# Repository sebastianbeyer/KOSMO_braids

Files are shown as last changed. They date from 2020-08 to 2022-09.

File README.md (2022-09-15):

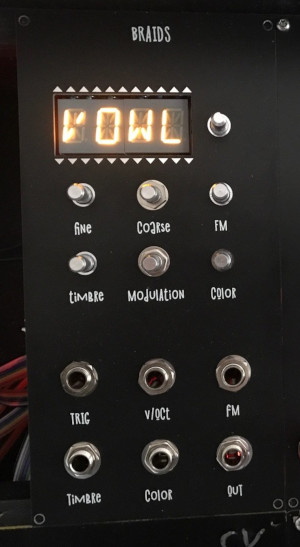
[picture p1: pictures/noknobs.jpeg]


This is a KOSMO (Look Mum No Computer) version of the Mutable instruments
braids, based on the through-hole version done by
[sound-force.nl](http://sound-force.nl/?page_id=3179).
It has only 12 bits resolution in the output because the chip is easier to work
with and cheaper.

## Changes to original

This project is so far only different to the soundforce version in that I removed the
3.5mm jack sockets and replaced them with molex connectors to get them connected to the
larger 6.3mm jack sockets that KOSMO uses.
And I made the larger KOSMO panel.

This version is still with the old (soundforce-1.1) Version of the soundforce board, without the
termination series resistors on the SPI lines. I had no problems with this, but
I have not changed anything on the BRAIN board, so you can just use the original
gerbers.

## How to build:

Go download the latest gerber files
[here](https://github.com/sebastianbeyer/KOSMO_braids/releases/latest) and use
them to order PCBs. If you use jlcpcb to order, make sure you check "Specify a
location" at "Remove Order Number" for the panel.

For documentation and BOM look at
[sound-force.nl](http://sound-force.nl/?page_id=3179).

## How to program:

BratAttack made an awesome video on how to upload the firmware to the STM32!
BratAttackVideo (http://www.youtube.com/watch?v=kT_u0w2BjEw "Putting Firmware on KOSMO Braids")

## Changelog

### 1.1
Compared to the version in the top picture, I have made the cutout for the
display a little bit smaller and added small "+" and "-" indicators for
modulation and FM.

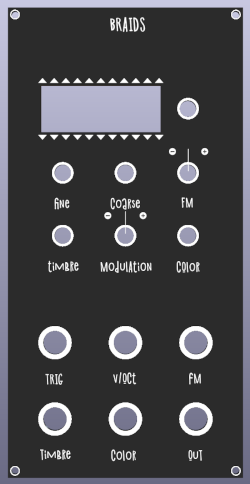
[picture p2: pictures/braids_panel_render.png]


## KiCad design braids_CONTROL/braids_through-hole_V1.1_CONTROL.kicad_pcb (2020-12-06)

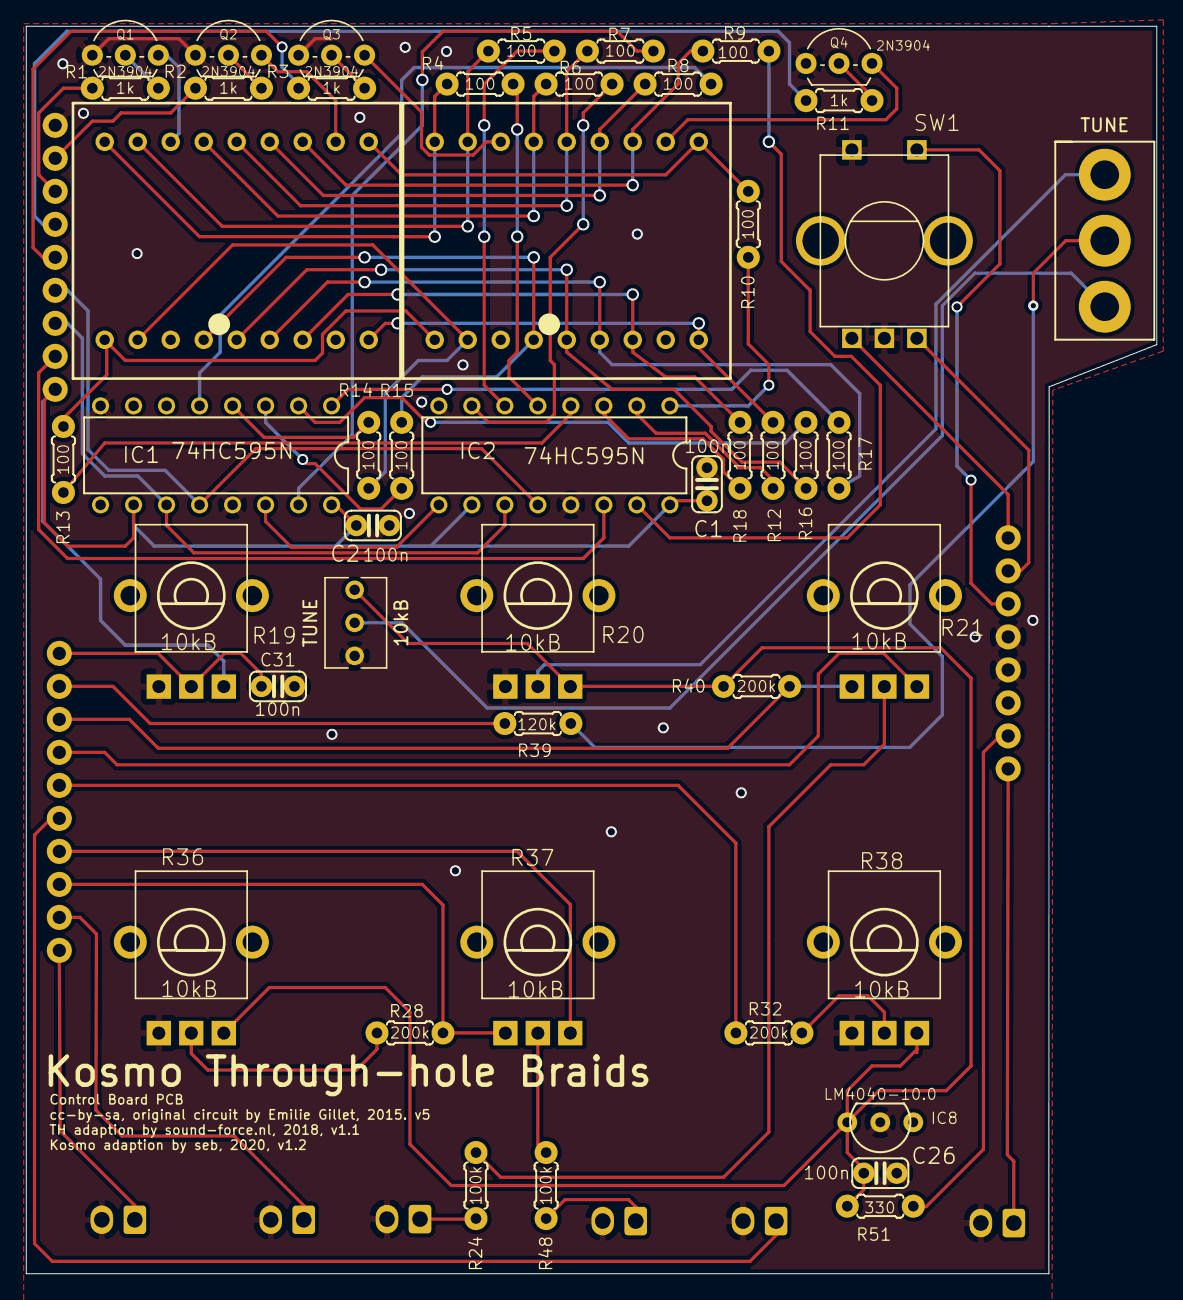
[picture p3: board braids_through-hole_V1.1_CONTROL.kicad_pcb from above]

Board: 2 copper layers, 87.0 x 96.0 mm, 56 parts (0 on the bottom side), 71 nets.

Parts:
C1, C2, C26, C31: 100n; C025-024X044
COLOR: PJ301_THONKICONN6; Molex_KK-254_AE-6410-02A_1x02_P2.54mm_Vertical
DISP1, DISP2: KINGBRIGHT-PDC54-11; PDC54
DISP_C: 1X09
FM: PJ301_THONKICONN6; Molex_KK-254_AE-6410-02A_1x02_P2.54mm_Vertical
IC1, IC2: 74HC595N; DIL16
IC8: LM4040-10.0; TO127P254X495-3
IN_C: 1X10
OUT: PJ301_THONKICONN6; Molex_KK-254_AE-6410-02A_1x02_P2.54mm_Vertical
PIN_C: 1X08
Q1, Q2, Q3, Q4: 2N3904; TO92-CBE
R1, R2, R3, R11: 1k; 0204_5
R4, R5, R6, R7, R8, R9, R10, R12, R13, R14, R15, R16, R17, R18: 100; 0204_5
R19, R20, R21, R36, R37, R38: 10kB; ALPS_POT_VERTICAL_PS
R24, R48: 100k; 0204_5
R28, R32, R40: 200k; 0204_5
R39: 120k; 0204_5
R51: 330; 0204_5
SW1: EC12E_SW; ALPS_EC12E_SW
TIMBRE: PJ301_THONKICONN6; Molex_KK-254_AE-6410-02A_1x02_P2.54mm_Vertical
TRIG: PJ301_THONKICONN6; Molex_KK-254_AE-6410-02A_1x02_P2.54mm_Vertical
TUNE: SPST SWITCH; SPDT SWITCH
TUNE#2: 10kB; Potentiometer_Bourns_3266Y_Vertical
VOCT: PJ301_THONKICONN6; Molex_KK-254_AE-6410-02A_1x02_P2.54mm_Vertical

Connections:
+3V3_1: C1.1, C2.1, DISP_C.1, IC1.10, IC1.16, IC2.10, IC2.16, R19.P$1
AREF_-10: C26.1, IC8.ANODE, R20.P$1, R36.P$1, R38.P$1, R51.2, TUNE#2.1
COLOR_JACK_1: COLOR.1, IN_C.5
COLOR_POT_1: IN_C.6, R32.2
DISP_CHAR0_1: DISP_C.5, R3.1
DISP_CHAR1_1: DISP_C.6, R11.1
DISP_CHAR2_1: DISP_C.7, R1.1
DISP_CHAR3_1: DISP_C.8, R2.1
DISP_EN_1: DISP_C.4, IC1.12, IC2.12
DISP_SCK_1: DISP_C.3, IC1.11, IC2.11
DISP_SER_1: DISP_C.2, IC2.14
ENC_A_1: PIN_C.2, SW1.B
ENC_B_1: PIN_C.1, SW1.A
ENC_CLICK_1: PIN_C.3, SW1.E
FINE_TUNE_1: C31.1, IN_C.10, R19.P$2
FM_JACK1: FM.1, R24.1
FM_POT_A_1: IN_C.7, R21.P$1
FM_POT_B_1: IN_C.8, R21.P$3, R40.2
GND: C1.2, C2.2, C26.2, C31.2, COLOR.2, DISP_C.9, FM.2, IC1.8, IC1.13, IC2.8, IC2.13, IC8.CATHODE, OUT.2, PIN_C.4, PIN_C.5, Q1.E, Q2.E, Q3.E, Q4.E, R19.P$3, R20.P$3, R36.P$3, R38.P$3, SW1.C, SW1.D, TIMBRE.2, TRIG.2, TUNE#2.3, VOCT.2
unnamed: DISP2.16, Q3.C
unnamed: DISP2.11, Q4.C
unnamed: DISP1.16, Q1.C
unnamed: DISP1.11, Q2.C
unnamed: Q3.B, R3.2
unnamed: Q4.B, R11.2
unnamed: Q1.B, R1.2
unnamed: Q2.B, R2.2
unnamed: DISP1.12, DISP2.12, R9.2
unnamed: DISP1.10, DISP2.10, R10.2
unnamed: DISP1.9, DISP2.9, R12.2
unnamed: DISP1.7, DISP2.7, R18.2
unnamed: DISP1.1, DISP2.1, R13.2
unnamed: DISP1.18, DISP2.18, R4.2
unnamed: DISP1.17, DISP2.17, R5.2
unnamed: DISP1.15, DISP2.15, R6.2
unnamed: DISP1.14, DISP2.14, R7.2
unnamed: DISP1.6, DISP2.6, R17.2
unnamed: DISP1.5, DISP2.5, R16.2
unnamed: DISP1.4, DISP2.4, R15.2
unnamed: DISP1.2, DISP2.2, R14.2
unnamed: DISP1.13, DISP2.13, R8.2
unnamed: IC2.7, R6.1
unnamed: IC1.14, IC2.9
unnamed: IC2.15, R9.1
unnamed: IC2.1, R10.1
unnamed: IC2.2, R12.1
unnamed: IC2.3, R18.1
unnamed: IC2.4, R13.1
unnamed: IC2.5, R4.1
unnamed: IC2.6, R5.1
unnamed: IC1.15, R7.1
unnamed: IC1.1, R17.1
unnamed: IC1.2, R16.1
unnamed: IC1.3, R15.1
unnamed: IC1.4, R14.1
unnamed: IC1.5, R8.1
unnamed: R21.P$2, R24.2
unnamed: R28.1, R36.P$2
unnamed: R37.P$2, R48.2
unnamed: R32.1, R38.P$2
OUT_1: OUT.1, PIN_C.8
TIMBRE_JACK_2: R48.1, TIMBRE.1
TIMBRE_POT_A_1: IN_C.4, R37.P$1
TIMBRE_POT_B_1: IN_C.3, R28.2, R37.P$3
TRIG_JACK_1: IN_C.1, TRIG.1
VEE_1: PIN_C.7, R51.1
VOCT_JACK_1: IN_C.2, VOCT.1
VOCT_POT_1: IN_C.9, R39.2
coarse_knob: R20.P$2, TUNE.1
trim: TUNE.3, TUNE#2.2
tune_sel: R39.1, TUNE.2

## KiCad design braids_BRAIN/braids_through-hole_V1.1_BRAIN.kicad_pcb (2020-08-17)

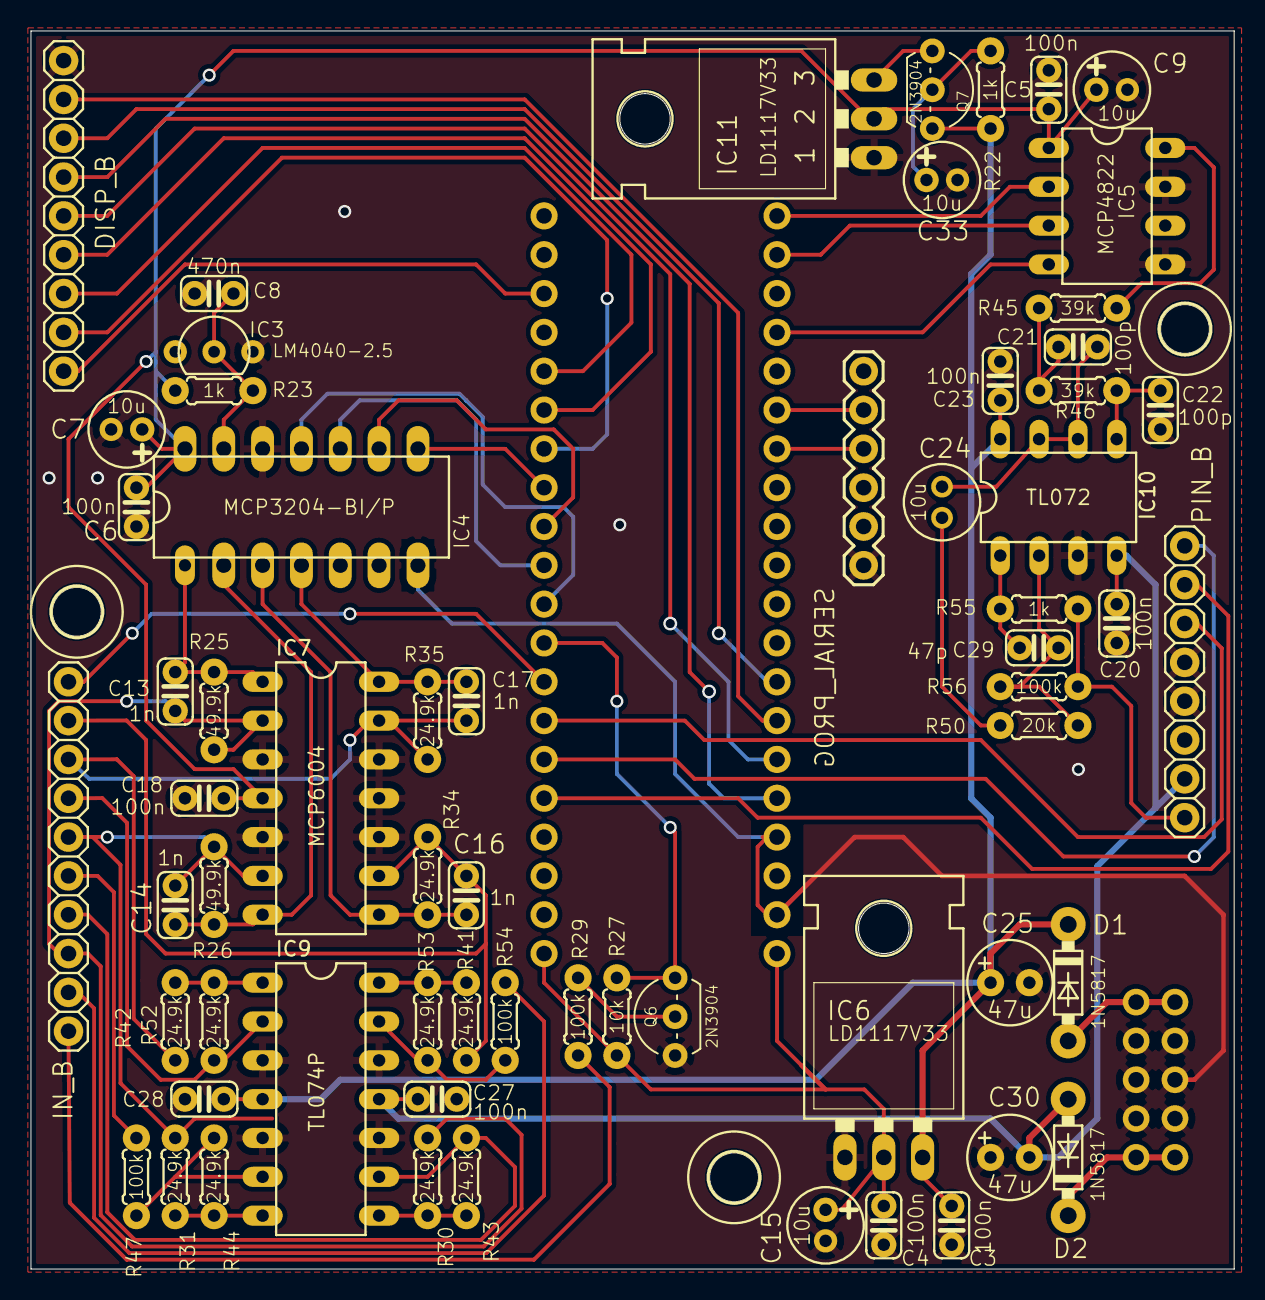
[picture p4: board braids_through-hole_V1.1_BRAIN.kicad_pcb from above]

Board: 2 copper layers, 78.7 x 81.0 mm, 68 parts (0 on the bottom side), 60 nets.

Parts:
C3, C4, C5, C6, C18, C20, C23, C27, C28: 100n; C025-024X044
C7, C9, C15, C33: 10u; E2-5
C8: 470n; C025-024X044
C13, C14, C16, C17: 1n; C025-024X044
C21, C22: 100p; C025-024X044
C24: 10u; E2-5_NP
C25, C30: 47u; E2,5-6
C29: 47p; C025-024X044
D1, D2: 1N5817; DO41-7.6
DISP_B: 1X09
IC3: LM4040-2.5; TO127P254X495-3
IC4: MCP3204-BI/P; DIP254P762X432-14
IC5: MCP4822
IC6, IC11: LD1117V33; TO220L1
IC7: MCP6004; DIL14
IC9: TL074P; DIL14
IC10: TL072; DIL08
IN_B: 1X10
PIN_B: 1X08
PWR: EURO
Q6, Q7: 2N3904; TO92-CBE
R22, R23, R55: 1k; 0204_5
R25, R26: 49.9k; 0204_5
R27: 10k; 0204_5
R29, R47, R54, R56: 100k; 0204_5
R30, R31, R34, R35, R41, R42, R43, R44, R52, R53: 24.9k; 0204_5
R45, R46: 39k; 0204_5
R50: 20k; 0204_5
SERIAL_PROG: 1X06
U$2, U$3, U$5: 3,2
UC1: STM32F103C8T6

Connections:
+3V3: C4.1, C15.+, IC6.2, R27.2, UC1.3.3V2, UC1.VBAT
+3V3A: C5.1, C6.1, C7.+, C9.+, C18.1, IC4.14, IC5.VCC, IC7.4, IC11.2, R23.1
+3V3_2: DISP_B.1, UC1.3.3V
ADC_MISO: IC4.10, UC1.PA6
ADC_MOSI: IC4.9, UC1.PA7
ADC_SCK: IC4.11, UC1.PA5
ADC_SS: IC4.8, UC1.PB0
AREF: C8.1, IC3.CATHODE, IC4.13, R23.2
AUDIO_OUT: IC5.VOUTA, R45.2
COLOR_JACK_2: IN_B.5, R47.1
COLOR_POT_2: C14.1, IC7.6, IN_B.6, R26.1, R31.2
DAC_MOSI: IC5.SDI, UC1.PB15
DAC_SCK: IC5.SCK, UC1.PB13
DAC_SS: IC5.CS, UC1.PB12
DISP_CHAR0: DISP_B.5, UC1.PB7
DISP_CHAR1: DISP_B.6, UC1.PB8
DISP_CHAR2: DISP_B.7, UC1.PB5
DISP_CHAR3: DISP_B.8, UC1.PB6
DISP_EN: DISP_B.4, UC1.PB10
DISP_SCK: DISP_B.3, UC1.PB11
DISP_SER: DISP_B.2, UC1.PB1
ENC_A: PIN_B.2, UC1.PA0
ENC_B: PIN_B.1, UC1.PA1
ENC_CLICK: PIN_B.3, UC1.PA2
FINE_TUNE_2: IN_B.10, UC1.PA3
FM_CV: C17.2, IC4.4, IC7.14, R35.2
FM_POT_A_2: IC9.2, IN_B.7, R52.1
FM_POT_B_2: C17.1, IC7.13, IN_B.8, R35.1, R42.2
GATE: Q6.C, R27.1, UC1.PA4
GND: C3.2, C4.2, C5.2, C6.2, C7.-, C8.2, C9.-, C15.-, C18.2, C20.1, C22.2, C23.2, C25.-, C27.1, C28.2, C30.+, C33.-, DISP_B.9, IC3.ANODE, IC4.7, IC4.12, IC5.GND, IC5.LDAC, IC6.1, IC7.3, IC7.5, IC7.10, IC7.11, IC7.12, IC9.3, IC9.5, IC9.10, IC9.12, IC10.3, IC11.1, PIN_B.4, PIN_B.5, PWR.3, PWR.4, PWR.5, PWR.6, PWR.7, PWR.8, Q6.E, SERIAL_PROG.1, UC1.GND3, UC1.PB9
unnamed: IC11.3, Q7.E
unnamed: C33.+, Q7.B, R22.1
unnamed: IC9.14, R41.1, R53.2
unnamed: IC9.13, R53.1, R54.2
unnamed: IC9.8, R30.1, R43.2
unnamed: IC9.1, R42.1, R52.2
unnamed: D1.A, PWR.1, PWR.2
unnamed: IC9.7, R31.1, R44.2
unnamed: IC9.6, R44.1, R47.2
unnamed: D2.C, PWR.9, PWR.10
unnamed: Q6.B, R29.2
unnamed: C21.2, C24.+, IC10.6, IC10.7
unnamed: C24.-, R50.2
unnamed: C22.1, IC10.5, R46.1
unnamed: C21.1, R45.1, R46.2
unnamed: C29.2, IC10.1, R55.2
unnamed: C29.1, IC10.2, R50.1, R56.2
OUT: PIN_B.8, R55.1, R56.1
PARAM1_CV: C13.2, IC4.1, IC7.1, R25.2
PARAM2_CV: C14.2, IC4.2, IC7.7, R26.2
PITCH_CV: C16.2, IC4.3, IC7.8, R34.2
RX: SERIAL_PROG.4, UC1.PA10
TIMBRE_POT_A_2: IC9.9, IN_B.4, R43.1
TIMBRE_POT_B_2: C13.1, IC7.2, IN_B.3, R25.1, R30.2
TRIG_JACK_2: IN_B.1, R29.1
TX: SERIAL_PROG.5, UC1.PA9
VCC: C3.1, C23.1, C25.+, C28.1, D1.C, IC6.3, IC9.4, IC10.8, Q7.C, R22.2
VEE: C20.2, C27.2, C30.-, D2.A, IC9.11, IC10.4, PIN_B.7
VOCT_JACK_2: IN_B.2, R54.1
VOCT_POT_2: C16.1, IC7.9, IN_B.9, R34.1, R41.2

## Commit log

2020-08-17 initial with panel stuff
    [braids_panel.kicad_pcb, braids_panel.sch]
2020-08-17 rename panel dir
    [braids_panel.kicad_pcb, braids_panel.sch]
2020-08-17 add changes in silkscreen
    [braids_panel.kicad_pcb]
2020-08-17 add control folder
    [braids_through-hole_V1.1_CONTROL.kicad_pcb]
2020-08-17 add brain board
    [braids_through-hole_V1.1_BRAIN.kicad_pcb]
2020-12-06 add trim switch
    [braids_panel.kicad_pcb, braids_panel.sch, braids_through-hole_V1.1_CONTROL.kicad_pcb]
2020-12-06 dont know kicad stuff
    [braids_panel.sch, braids_through-hole_V1.1_CONTROL.kicad_pcb]

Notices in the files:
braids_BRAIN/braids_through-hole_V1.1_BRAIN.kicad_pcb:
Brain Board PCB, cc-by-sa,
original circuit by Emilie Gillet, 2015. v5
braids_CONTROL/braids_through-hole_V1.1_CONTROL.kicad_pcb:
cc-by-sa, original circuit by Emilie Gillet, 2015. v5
